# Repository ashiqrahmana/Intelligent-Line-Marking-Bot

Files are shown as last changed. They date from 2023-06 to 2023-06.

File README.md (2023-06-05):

# iLMBt - Intelligent Line Marking Bot
iLMBt (intelligent Line Marking Bot) is an autonomous wheeled mobile robot designed specifically for marking lines on sports fields without the need for human intervention. This GitHub repository contains all the necessary code, documentation, and design files to build and operate the iLMBt robot.

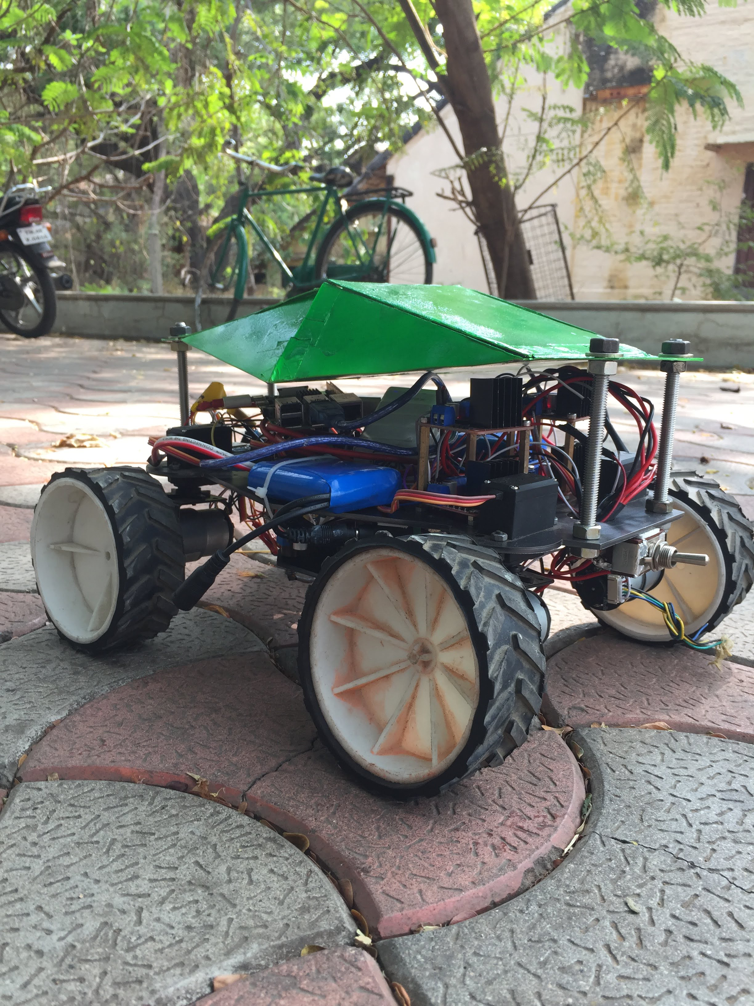
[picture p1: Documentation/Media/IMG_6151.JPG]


## Project Overview
The primary objective of iLMBt is to automate the line marking process in sports fields. By eliminating the need for human labor, iLMBt offers increased efficiency, precision, and reliability in line marking tasks. The robot utilizes a hopper mechanism controlled by a motorized lead screw to control the flow of marking powder. It also incorporates an effective dampening system for smooth and consistent line marking operations.

## Features
* **Autonomous line marking**: iLMBt is capable of autonomously marking lines on sports fields based on given coordinates. It calculates the desired path and precisely marks the required lines.
* **Collision avoidance**: The robot is equipped with a collision avoidance program that works in conjunction with the path tracking algorithm. This allows iLMBt to maneuver smoothly around obstacles while reaching the designated starting point.
* **Improved accuracy**: With the use of advanced navigation technologies such as GPS, IMU, and encoders, iLMBt ensures high accuracy in line marking, resulting in professionally marked sports fields.
* **Sensor integration**: iLMBt incorporates various sensors, including LIDAR, for obstacle avoidance and local mapping. These sensors enable the robot to navigate safely and efficiently. Accurate localisation was achieved using Kalman filter.

## Hardware and Electronics
* **Raspberry Pi**: The Raspberry Pi serves as the main controller for iLMBt, handling higher-level tasks such as path planning and communication.
* **Arduino Mega**: The Arduino Mega is responsible for low-level control and interfacing with the robot's actuators and sensors.
* **GPS**: A GPS module is used for global positioning, allowing iLMBt to determine its precise location on the sports field.
* **IMU**: An IMU (Inertial Measurement Unit) provides orientation and motion data, contributing to accurate navigation.
* **Encoder**: Encoders are employed for precise wheel odometry, enabling the robot to track its position and distance traveled.
* **LIDAR**: The LIDAR sensor enables iLMBt to detect obstacles and create a local map of its surroundings for effective collision avoidance.

## Contributions
Contributions to the iLMBt project are welcome! If you have any improvements, bug fixes, or new features to contribute, please follow the guidelines outlined in the Contribution document. Your contributions will be greatly appreciated and help advance the capabilities of iLMBt.

## Contact
For any questions, suggestions, or collaborations, please feel free to contact the project maintainers:

Ashiq Rahman: ashiqrahmanab@gmail.com
Thank you for your interest in iLMBt! We hope this project brings automation and improved line marking capabilities to sports fields worldwide.

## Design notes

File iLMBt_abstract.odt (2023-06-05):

iLMBt

iLMBt (intelligent Line Marking Bot) is an autonomous wheeled mobile robot that is modeled and designed to mark the lines of sports fields without any human intervention.

A hopper mechanism is built in to control the flow of powder, which is controlled by a motorized lead screw. An effective dampening system is designed for the smooth operation of the robot.

With the given coordinates, iLMBt calculates the desired path and the required line is marked.

A collision avoidance program is included with the path tracking algorithm to smoothly maneuver around obstacles while reaching the required starting point.

iLMBt eliminates the human labor in marking sports fields and also improves the accuracy of the lines.

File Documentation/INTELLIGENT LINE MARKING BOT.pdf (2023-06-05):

## INTELLIGENT LINE MARKING BOT

Team member details:

S.No | Name | Roll Number | Year | Department | Mail ID | Phone Number
1. | Ashiq Rahman.A | 2018111015 | 3 | Mechanical | ashiqrahman741 @gmail.com | 6379404556
2. | Rajadurai.B | 2018111086 | 3 | Mechanical | brdrccegmotorsp orts@gmail.com | 9488624177
3. Vasanth | Kumar.V | 2019105064 | 2 | Electronics and Communication | vasanthvv1717 @gmail.com | 9445032825
4. Nithish | Narayan.S | 2019118020 | 2 | Mechanical | nithishnarayan2 001@gmail.com | 7358129293
5. Harshaward | han.K.U | 2018111044 | 3 | Mechanical | harshaku2001@ gmail.com | 6385666123
6. | Veniniyan.V | 2018111127 | 3 | Mechanical | veniniyan1729 @gmail.com | 8248725604
7. | Vallarasu.K | 2018111125 | 3 | Mechanical | vallarasukumar2 001@gmail.com | 7339074190

Abstract:

Nowadays, robots are used in different areas for different applications. The problem is to mark field lines manually in a sports field, especially on gravel or sand fields, which can lead to errors and high time consumption. This project thus focuses on a stand-alone line marking robot, which can easily complete this process. This robot is intended to provide accurate marking of any field within a shorter time frame by using sensor fusion algorithms to fuse various sensors to pinpoint the location of the robot. The simulation of the robot is performed in the Matlab - Simulink software with the help of existing libraries. After the simulation, the code is checked on a real robot. The mechanical team developed the design. Adequate suspension and steering mechanisms will be provided to overcome the unequal nature of ground or soil. Finally, the code has been optimised and tested in the field to achieve the desired precision.

YouTube Link and Website Link:

Bot | CTF Projects | Kurukshetra '21 - YouTube (https://www.youtube.com/watch?v=S4F7P6YnfdU&ab_channel=KurukshetraCEG)

Link to the LOA folder:

Timeline:

DECEMBER | Simulation on MATLAB - SIMULINK software.
JANUARY | Initial Design and Testing iterations of the bot in CAD software

FEBRUARY | Final Design and Testing iterations of the bot in CAD software
MARCH | Assembly and Testing of the Bot

SPLIT UP WORKS: -

We, the team members, had a number of brainstorming sessions on G-Meet. Analysed the pros and cons of different components and concepts used in the bot.

We internally split up our work as two parts

a) Design Team
b) Simulation and Coding Team

Though we split work among ourselves, we consistently had many meetings during weekdays and weekends to share our work process and had many discussions on the improvement of the bot.

DECEMBER (SIMULATION): -

WEEK 1: -

The Problem statement was further analysed and tried to formulate the most feasible solution with the team. Discussed about the essential works to be done for the bot’s successful operation.

WEEK 2: -

Initial iteration of the pre-path planning algorithm was done. This includes creating way points for the bot to trace.

WEEK 3: -

The code for the pre-path planning algorithm was successfully finished.

WEEK 4: -

Initial iteration of Sensor fusion of Magnetometer, Gyroscope and Accelerometer was simulated in MATLAB.

JANUARY (DESIGN AND TESTING): -

WEEK 1: -

Sensor fusion was successfully simulated in MATLAB. Noise of the sensor was reduced by different filters.

WEEK 2: -

Analysed and discussed with the team about the designing works of the bot and initial iterations of design were formed.

Potential components required were drafted.

WEEK 3: -

1. Finished the CAD design works of iLMBT.
2. Analysed the CAD model and its performance on the track.
3. Done important calculations and analysis in kinematics.

WEEK 4: -

1. According to the calculation the bot was completely redesigned.
2. Finalize the chassis, wheelbase, knuckle type
3. And materials were selected for each and every major component.

FEBRUARY (DESIGN AND TESTING Contd.): -

WEEK 1: -

Many design iterations were made to rectify all the minute corrections.

WEEK 2: -

Studied about the closing and opening of the powder entrance. And finalized to use the Hopper mechanism and studied it further.

WEEK 3: -

1. Finalized the components required and suitable for the Hopper mechanism like N20 motor (to open and close the hopper slot) and calculated the dimensions of the slots needed.
2. Servo motors were used for steering of each wheel, it can make upto 45 degrees of rotation.

WEEK 4: -

Finalised the materials and dimensions suitable for the chassis tank. Did some mass calculations on the hole (where the powder will be deployed) of iLMBT.

MARCH (ASSEMBLY AND TESTING): -

WEEK 1: -

- Electronic component mounting design was added to the existing design of the bot.
- Several iterations of the design were done for effective placement of the electronic components.

WEEK 2: -

- The layout design for laser cut was done and it took a week to get all the material for laser cutting.
- All the electronic components of the bot arrived. Such as Arduino mega, Raspberry pi, Motor drivers, GPS Module, MPU 9250, Gyro, Servo motor for steering and wheels.
- Meanwhile the code was uploaded in Raspberry pi and Arduino and checked for errors and corrected.

WEEK 3: -

- The chassis of the bot was laser cut.

- The fit and tolerance of the electronic component was tested with the chassis of the bot.
- Initial assembly of the electronics was made and all the parts were tested. Such as a GPS module.
- All necessary parts of the bot arrived such as Wheels, rechargeable batteries.
- The holes in the chassis were 2.7mm but the actual diameter needed was 3mm. So, the chassis was drilled to enlarge the dimensions.
- The wheels were attached to the chassis with servo to check the camber of the wheels and the deflection of the chassis.

WEEK 4: -

- The casing of the bot was done.
- The bot was checked for steering and GPS status.
- The initial testing of the bot was done on the field.
- All the wires are disassembled and proper soldering was done.
- Hopper mechanism was fixed and the top case was attached to the bot.
- The bot was finished with all required parts and assembly.

Budget:

S.N o. | Component Name | Shop Name with Location | Per Unit Price | Quantity | Net Price
1. | MPU 9250 | Mercy Electronics | Rs.661.02 | 1 | Rs.661.02
2. P.Kit GPS Flight | Control | Mercy Electronics | Rs.406.78 | 1 | Rs.406.78
3. Triple axis Gyro | Accelerometer Module | ElectronicsComp.in | Rs.83.00 | 1 | Rs.83.00

4. Triple axis Compass | Magnetometer Sensor Module | ElectronicsComp.in | Rs.210.00 | 1 | Rs.210.00
5. | Arduino Mega | ElectronicsComp.in | Rs.695.00 | 1 | Rs.695.00
6. Raspberry Pi 4 Model B | with 2GB Ram | ElectronicsComp.in | Rs.2,895.00 | 1 | Rs.2,895.00
7. GA12 N20 12V | 140RPM All metal Gear Micro DC Encoder Motor | Dazzle Robotics | Rs.380.00 | 6 | Rs.2,280.00
8. Charger for | Rechargeable batteries | Amazon.in | Rs.675.00 | 1 | Rs.675.00
9. | TS10A 2P2W | Ponniie Electrical and Electronics | Rs.60.00 | 3 | Rs.212.40
10. Rhino GB37 12V | 110RPM 6.5KGCM DC Geared Encoder Servo Motor | Dazzle Robotics | Rs.810.00 | 4 | Rs.3,240.00
11. Li-ion 11.1V 2500mAh | (2C) with inbuilt charger protection | Dazzle Robotics | Rs.713.00 | 3 | Rs.2,139.00
12. Bracket for High | Torque/Side shaft Motor | Dazzle Robotics | Rs.120.00 | 4 | Rs.480.00
13. Jumper Cable Male to | Male | Mercy Electronics | Rs.135.69 | 1 | Rs.135.69

14. Jumper Cable Female to | Male | Mercy Electronics | Rs.5.60 | 10 | Rs.50.60
15. Jumper Cable Female to | Female | Mercy Electronics | Rs.5.60 | 10 | Rs.50.60
16. | Battery 9V | Mercy Electronics | Rs.12.71 | 1 | Rs.12.71
17. | Battery Snap 9V | Mercy Electronics | Rs.4.24 | 1 | Rs.4.24
18. Rhino DC Servo Driver | 50W | Dazzle Robotics | Rs.478.00 | 4 | Rs.1912.00
19. Hopper Made of | Aluminium Sheet | JNS Metals | Rs.275.00 | 0.95Kg | Rs.275.00
20. | Chassis Laser cut | Dhanalakshmi Industries | Rs.1391.00 | 1 | Rs.1391.00
21. Stud and M8 Bolt and | Nut | Sri Velavan Engineering Works | Rs.130.00 | 4 | Rs.520.00
22. | M6 Bolt and Nut | Raj Industrial Enterprises | Rs.90.00 | 1 | Rs.90.00
25. | M2 Bolt and Nut | Raj Industrial Enterprises | Rs.3.00 | 10 | Rs.30.00
26. Tracked Wheels of | 110mm Diameter 45mm Width and 6mm ID | Dazzle Robotics | Rs.130.00 | 4 | Rs.520.00

27. | 6 SS Allen Bolt | AR Traders | Rs.2.15 | 60 | Rs.129.00
28. | 8 SS Allen Bolt | AR Traders | Rs.2.20 | 25 | Rs.55.00
29. | 12 SS Allen Bolt | AR Traders | Rs.2.25 | 20 | Rs.45.00
30. | P.Kit Robot Chassis | Mercy Electronics | Rs.338.00 | 1 | Rs.338.00
31. | 15 SS Allen Bolt | AR Traders | Rs.4.50 | 20 | Rs.90.00
32. | 3mm GP Nut | AR Traders | Rs.0.25 | 40 | Rs10.00
33. | Memory Card 32GB | Poorvika Mobiles | Rs.600.00 | 1 | Rs.600.00
34. Material Milling and | Lathe Work | Skilled Engineering | Rs.600.00 | 1 | Rs.600.00
35. Electric Soldering Iron | Kit | Amazon.in | Rs.799.00 | 1 | Rs.799.00
36. | P.Kit Board | Mercy Electronics | Rs.161.00 | 1 | Rs.161.00
Total | | | | | Rs.21,795.64

Technical Explanation:

The Intelligent Line Marking bot (iLMBT) uses dynamic path planning algorithm, to plan the path in real time by avoiding obstacles and decreasing the time of line marking.

The bot uses Kalman filter which is a digital filter that filters error by accounting the probabilistic error of the GPS sensor (which has an accuracy of only 2.5m), IMU sensor which estimates to increase the accuracy to centimeter scale.

The bot has three sensors, they are GPS module, MPU9250 (which measures the angular velocity hence the rotation of the bot), and inbuilt compass to assess the orientation of the bot. The bot uses Akermann steering and Differential steering for kinematics of the system. It has a hopper tank with a capacity of 1.5 Kg, which helps in storage of line marking powder with minimal human interference. And this bot also has a ground clearance of 4.5m, which helps the bot work in uneven terrain. The bot uses N20 motors for smooth deployment of the powder in the field.

Photos of Components:

MPU 9250:

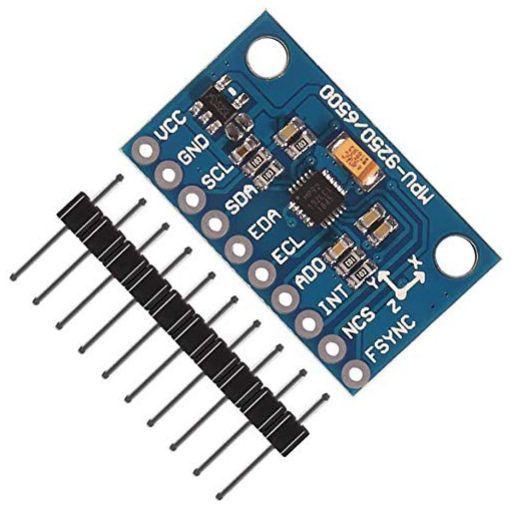
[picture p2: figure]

GPS module:

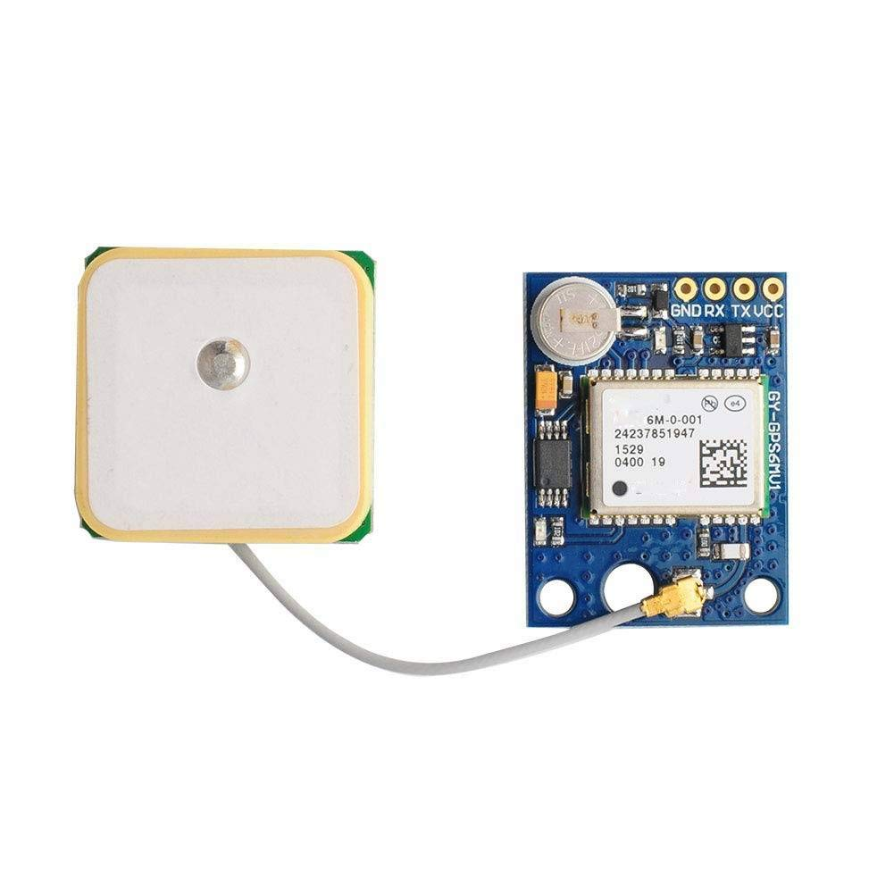
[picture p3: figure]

ARDUINO MEGA:

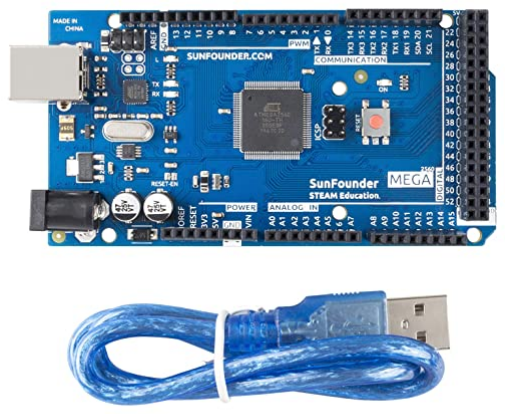
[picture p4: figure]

MOTOR DRIVER: -

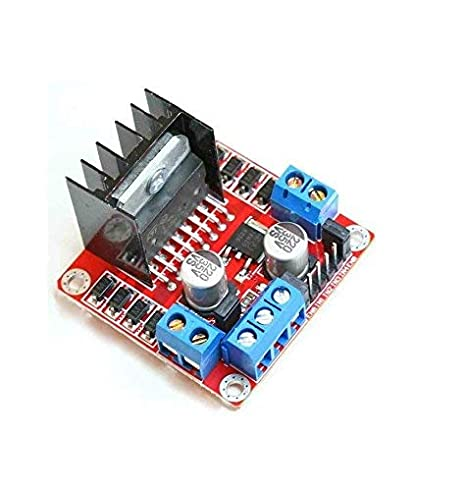
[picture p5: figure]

Triple axis Gyro Accelerometer Module: -

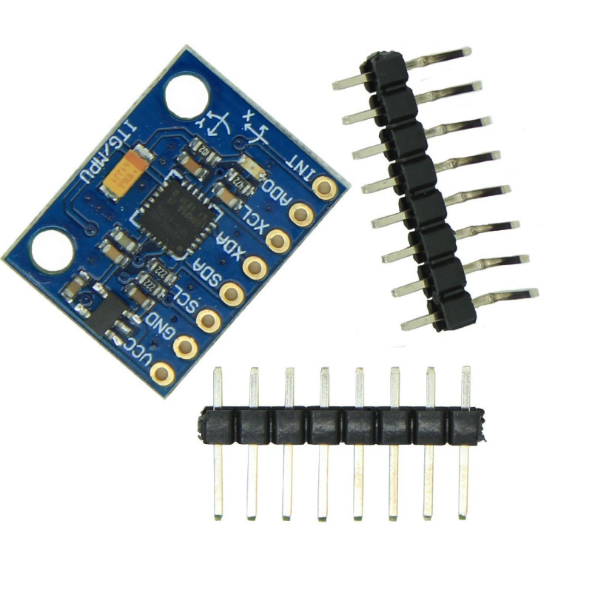
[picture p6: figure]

Analysis and Obtained Conclusions:

A1. The Kalman Filter has a large error to correct then usual mostly due to the present of trees

A2. There was a lot of vibration in the bot in general which should have been due to the lack of weight of the bot which lead to slipping of the wheel

Problems and Obtained Solutions:

P1. Actual dimension of the bot was not built.

P2. The deployment of line marking powder was not demonstrated.

P3. Obstacle detecting sensor was not added.

P4. Kalman filter was not tuned to full efficiency

Result:

The iLMBT was able to locate and move to two points successfully

Future Work:

- The iLMBT would be upgraded in size
- The steering motors will be upgraded due to less resolution in the present one
- Suspension systems are yet to added
- IOT code for the bot has to be done
- proper ventilation
- user interface

Attachment Details:

Team Folder -
https://drive.google.com/drive/folders/1LOc3MQuMsQAj66ATGowux1fOUP3XBcpq?usp=sharing (https://drive.google.com/drive/folders/1LOc3MQuMsQAj66ATGowux1fOUP3XBcpq?usp=sharing)

Media Folder -

https://drive.google.com/drive/folders/1bKW9zVyGzebHwZNid_FVrjj-9Q9dmMdC?usp=sharing (https://drive.google.com/drive/folders/1bKW9zVyGzebHwZNid_FVrjj-9Q9dmMdC?usp=sharing)

Guided By:

CTF Projects Student Directors

Sivakumar.S

Balaji.S

Hitesh Ram.A.K

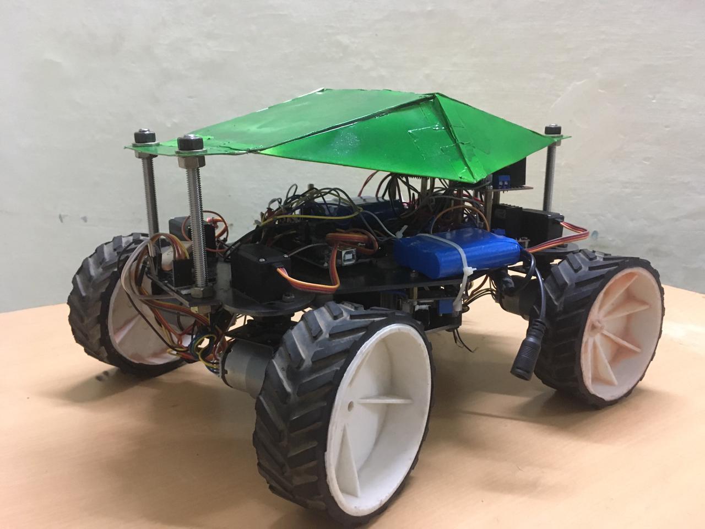
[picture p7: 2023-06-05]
Documentation/Media/WhatsApp Image 2021-03-28 at 3.16.44 AM.jpeg

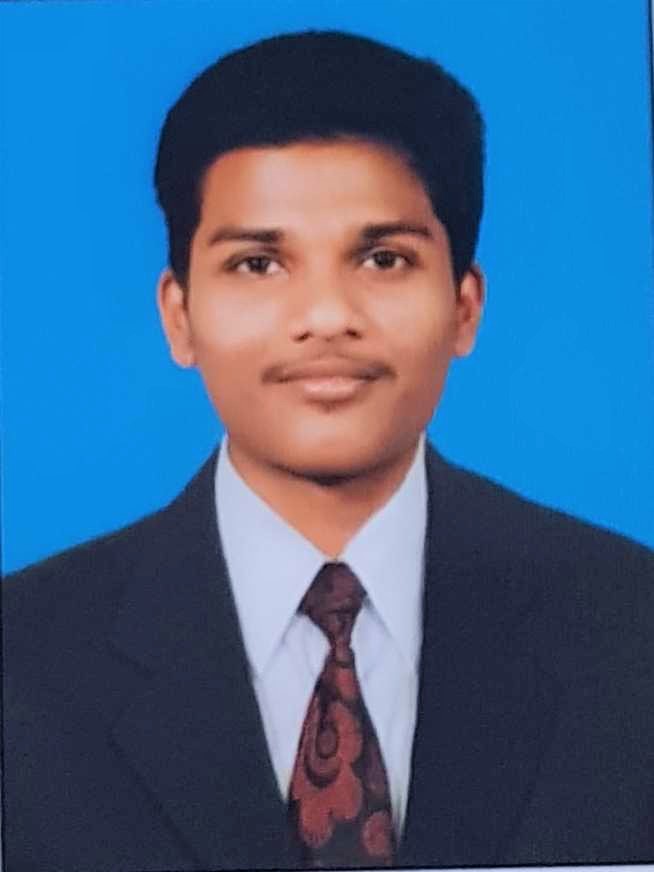
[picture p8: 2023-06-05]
Documentation/Team/Harshwardhan.jpeg

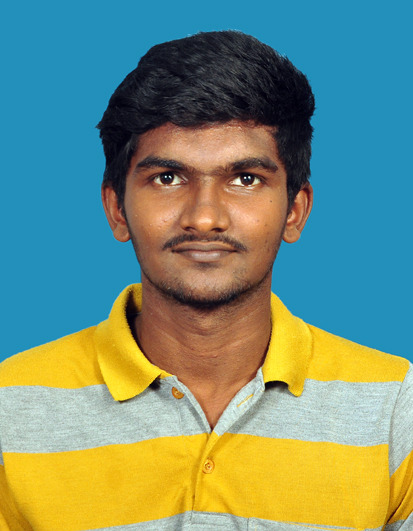
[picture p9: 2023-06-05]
Documentation/Team/Vasanth.jpeg

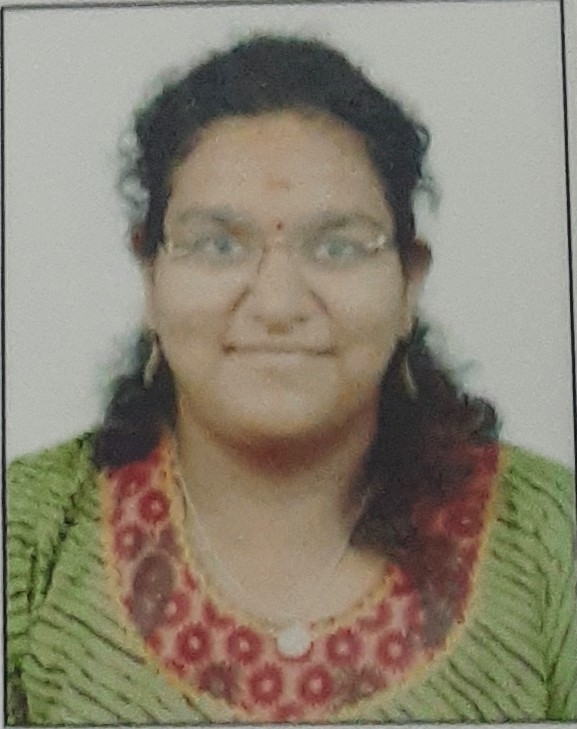
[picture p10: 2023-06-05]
Documentation/Team/Padmaja.jpg

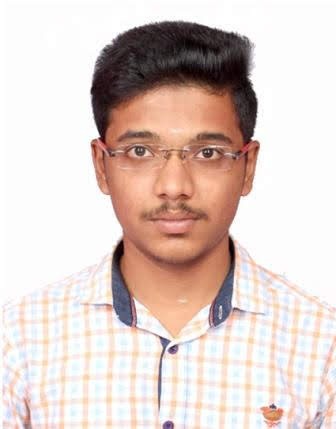
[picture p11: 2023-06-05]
Documentation/Team/Rajadurai.jpeg

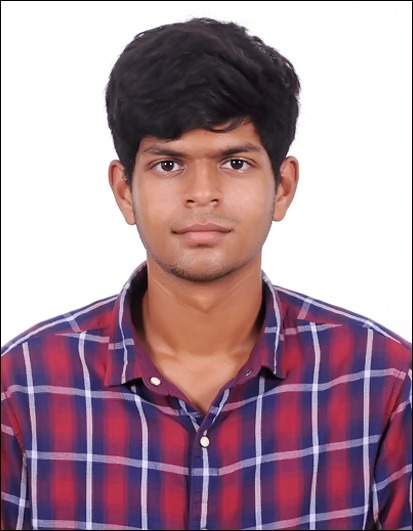
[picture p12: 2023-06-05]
Documentation/Team/Abdullah.jpeg

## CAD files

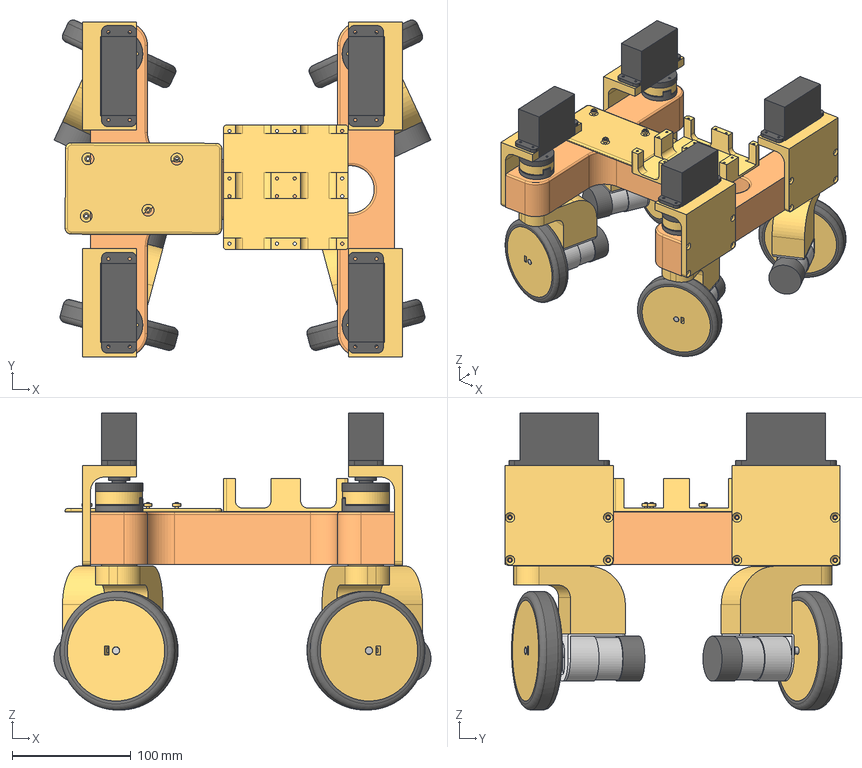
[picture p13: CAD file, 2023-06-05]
Design/3D cad xrobot version/OnmiSwerve-main/CAD/4_WheelsSwerve01.stp
317.7 x 284.0 x 250.2 mm
wheel
wheel(Mirror)
wheel(Mirror) (1)
wheel(Mirror)(Mirror)

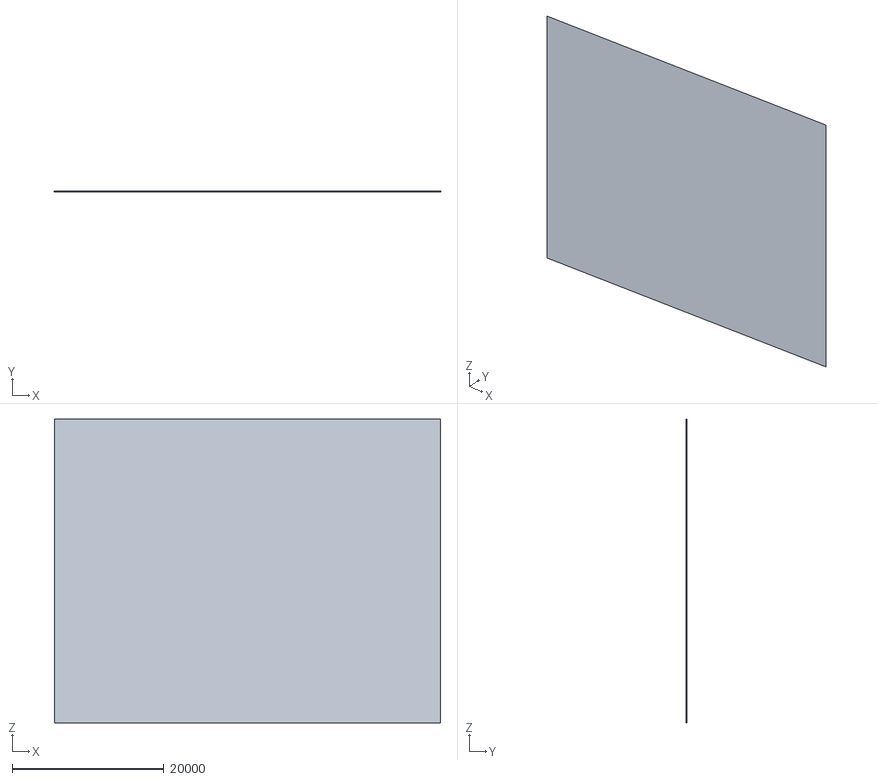
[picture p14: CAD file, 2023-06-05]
Design/Ground_Hockey/Ground.stl
50798.3 x 1.00 x 40005.7

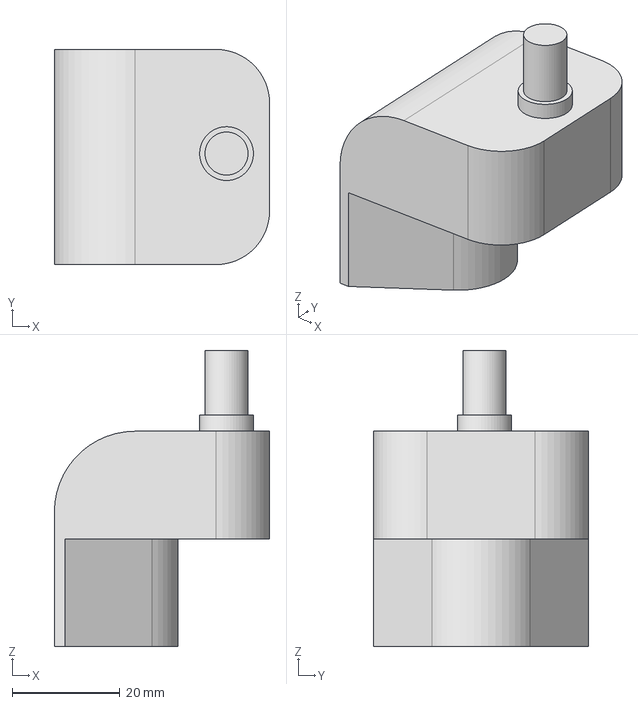
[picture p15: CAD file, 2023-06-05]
Design/ilmbt_3d_v1/servo_shaft.stp
40.0 x 40.0 x 55.0 mm

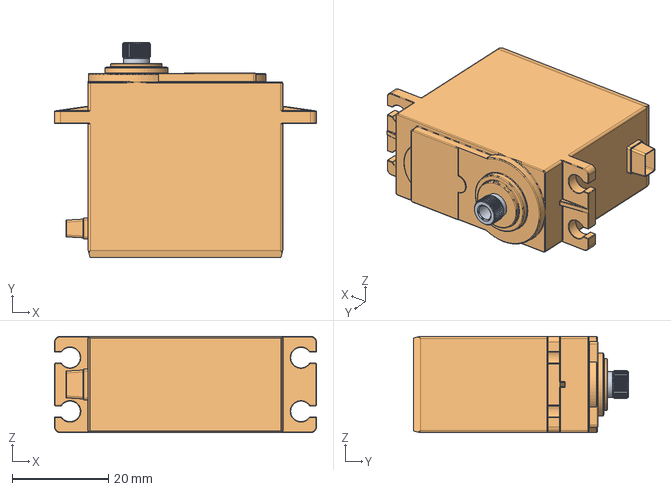
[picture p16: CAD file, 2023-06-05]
Design/LMBOT V3 80%/MG-958 servo_MIR.stp
54.4 x 44.6 x 20.0 mm
Golden part_MIR
Part13_MIR

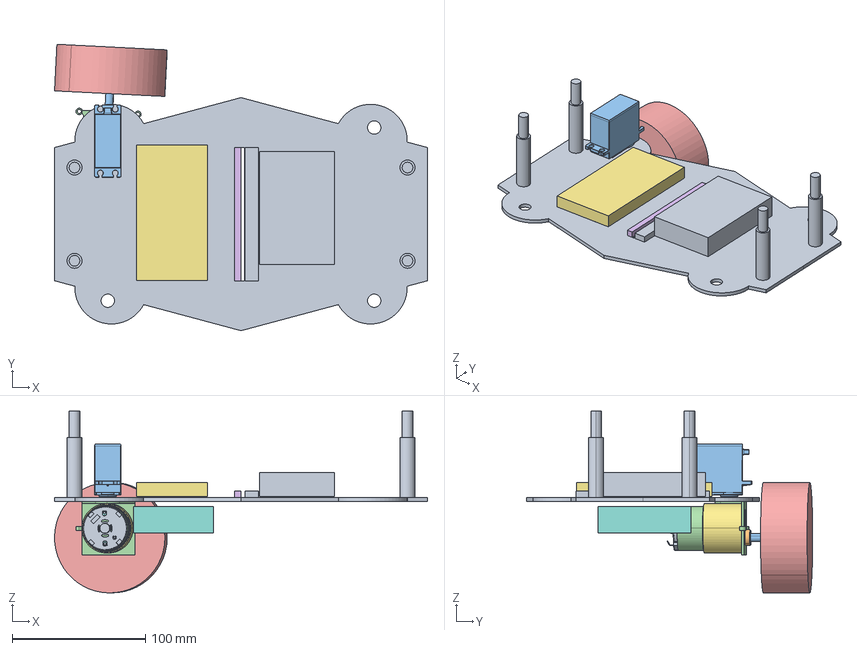
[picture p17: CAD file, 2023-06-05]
Design/LMbot V3/LMbot V3.stp
280.0 x 215.0 x 136.5 mm

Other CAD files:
Design/3D cad xrobot version/OnmiSwerve-main/CAD/4_WheelsSwerve01.iam
Design/3D cad xrobot version/OnmiSwerve-main/CAD/OldVersions/4_WheelsSwerve01.0007.iam
Design/3D cad xrobot version/OnmiSwerve-main/CAD/OldVersions/Part1.0002.ipt
Design/3D cad xrobot version/OnmiSwerve-main/CAD/OldVersions/Part10.0007.ipt
Design/3D cad xrobot version/OnmiSwerve-main/CAD/OldVersions/wheel(Mirror) (1).0001.ipt
Design/3D cad xrobot version/OnmiSwerve-main/CAD/OldVersions/wheel(Mirror)(Mirror).0001.ipt
Design/3D cad xrobot version/OnmiSwerve-main/CAD/OldVersions/wheel(Mirror).0001.ipt
Design/3D cad xrobot version/OnmiSwerve-main/CAD/OldVersions/wheel.0001.ipt
Design/3D cad xrobot version/OnmiSwerve-main/CAD/Part1.ipt
Design/3D cad xrobot version/OnmiSwerve-main/CAD/Part10.ipt
Design/3D cad xrobot version/OnmiSwerve-main/CAD/wheel(Mirror) (1).ipt
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

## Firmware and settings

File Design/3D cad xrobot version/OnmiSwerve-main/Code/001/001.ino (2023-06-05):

#include <Servo.h>

Servo servo1;
Servo servo2;
Servo servo3;
Servo servo4;

int wheel1;
int wheel1a;
int wheel2;
int wheel2a;

// Radio
#include <SPI.h>
#include <nRF24L01.h>
#include <RF24.h>

RF24 radio(7, 8); // CE, CSN
const byte addresses[][6] = {"00001", "00002"};

//**************remote control****************
struct RECEIVE_DATA_STRUCTURE{
  //put your variable definitions here for the data you want to send
  //THIS MUST BE EXACTLY THE SAME ON THE OTHER ARDUINO
    int16_t menuDown;  
    int16_t Select;    
    int16_t menuUp;  
    int16_t toggleBottom;  
    int16_t toggleTop; 
    int16_t toggle1;
    int16_t toggle2;
    int16_t mode;  
    int16_t RLR;
    int16_t RFB;
    int16_t RT;
    int16_t LLR;
    int16_t LFB;
    int16_t LT;
};

RECEIVE_DATA_STRUCTURE mydata_remote;

int RLR = 0;
float RFB = 0;
float RFBa = 0;
int RT = 0;
int LLR = 0;
int LFB = 0;
int LT = 0;
int LTa = 0;

float cor;
float insideAngle;
float outsideAngle;
float insideAngleOutput;
float outsideAngleOutput;
float insideVel;
float outsideVel;

unsigned long currentMillis;
long previousMillis = 0;    // set up timers
long interval = 10;        // time constant for timer

int servo1Offset = 1430;
int servo2Offset = 1375;
int servo3Offset = 1470;
int servo4Offset = 1500;

int servo45 = 400;

void setup() {

    pinMode(5, OUTPUT);
    pinMode(6, OUTPUT);
    pinMode(9, OUTPUT);
    pinMode(10, OUTPUT);
   
    // initialize serial communication
    Serial.begin(115200);
    
    radio.begin();
    radio.openWritingPipe(addresses[0]); // 00002
    radio.openReadingPipe(1, addresses[1]); // 00001
    radio.setPALevel(RF24_PA_MIN);
    radio.startListening();

    pinMode(3, OUTPUT);
    pinMode(4, OUTPUT);
    pinMode(5, OUTPUT);
    pinMode(6, OUTPUT);

    pinMode(9, OUTPUT);
    pinMode(10, OUTPUT);
    pinMode(11, OUTPUT);
    pinMode(12, OUTPUT);

    servo1.attach(32);
    servo2.attach(34);
    servo3.attach(36);
    servo4.attach(38);

    servo1.writeMicroseconds(servo1Offset);
    servo2.writeMicroseconds(servo2Offset);
    servo3.writeMicroseconds(servo3Offset);
    servo4.writeMicroseconds(servo4Offset);      


    
}   // end of setup

// ********************* MAIN LOOP *******************************

void loop() {  

      
        currentMillis = millis();
        if (currentMillis - previousMillis >= 20) {  // start timed event
          
            previousMillis = currentMillis;


            // check for radio data
            if (radio.available()) {
                    radio.read(&mydata_remote, sizeof(RECEIVE_DATA_STRUCTURE));   
            }             

            else {
              Serial.println("no data");
            }

            // threshold remote data
            // some are reversed based on stick wiring in remote
            RFB = (thresholdStick(mydata_remote.RFB))/2;   
            RLR = (thresholdStick(mydata_remote.RLR))/2;
            LT = (thresholdStick(mydata_remote.LT))/2;
            LLR = (thresholdStick(mydata_remote.LLR))/2; 


            if (mydata_remote.toggleTop == 1) {                       // rotate on the spot
                  
                servo1.writeMicroseconds(servo1Offset + servo45);
                servo2.writeMicroseconds(servo2Offset - servo45);
                servo3.writeMicroseconds(servo3Offset - servo45);
                servo4.writeMicroseconds(servo4Offset + servo45); 

                LT = LT / 1.5;        // scale driving stick some more

               if (LT >=0) {
                  LTa = abs(LT);
                  analogWrite(4, LTa);       // wheel 1
                  analogWrite(3, 0);
                  analogWrite(6, LTa);       // wheel 2
                  analogWrite(5, 0);
                  analogWrite(9, 0);       // wheel 3
                  analogWrite(10, LTa);
                  analogWrite(11, 0);       // wheel 4
                  analogWrite(12, LTa);
                  
                }

                else if (LT <=0) {
                  LTa = abs(LT);
                  analogWrite(4, 0);          // wheel 1
                  analogWrite(3, LTa);
                  analogWrite(6, 0);          // wheel 2
                  analogWrite(5, LTa);
                  analogWrite(9, LTa);       // wheel 3
                  analogWrite(10, 0);
                  analogWrite(11, LTa);       // wheel 4
                  analogWrite(12, 0);
                  
                }                         
            }

            else {                                                  // swerve steering

                // trig calcs for Ackermann steering
                
                cor = 1000-abs(LLR*3.5);                            // scale centre of rotation from stick

                insideAngle = atan(104 / (cor - 114));              // calc angle in radians
                insideAngle = insideAngle * (180/PI);               // convert to degrees    

                outsideAngle = atan(104 / (cor + 114));
                outsideAngle = outsideAngle * (180/PI);

                outsideAngle = outsideAngle * 9;                    // convert to servo ms
                insideAngle = insideAngle * 9;                      // convert to servo ms

                if (LLR == 0) {
                  insideAngleOutput = 0;                            // steer straight when the stick is in the middle
                  outsideAngleOutput = 0;
                } 
                else if (LLR >=0) {
                  insideAngleOutput = outsideAngle*-1;              // invert angles when we steer the other way
                  outsideAngleOutput = insideAngle*-1;
                }
                else if (LLR <=0) {
                  insideAngleOutput = insideAngle;                  // angles can be used for the default side of the vehicle as they are
                  outsideAngleOutput = outsideAngle;
                }

                Serial.print(insideAngle);
                Serial.print(" , ");
                Serial.println(outsideAngle);
 
           
                servo1.writeMicroseconds(servo1Offset + (LT * 3.8) - insideAngleOutput);        // write out the servo positions
                servo2.writeMicroseconds(servo2Offset + (LT * 3.8) + insideAngleOutput);        // use the left twist stick for swerve steering
                servo3.writeMicroseconds(servo3Offset + (LT * 3.8) - outsideAngleOutput);       // and use the angle calc for Ackermann steering.
                servo4.writeMicroseconds(servo4Offset + (LT * 3.8) + outsideAngleOutput); 



                insideVel = float ((RFB/100)*outsideAngle);
                outsideVel = float ((RFB/100)*insideAngle);
                insideVel = constrain(insideVel,-255,255);
                outsideVel = constrain(outsideVel,-255,255);



                // write to motors 
               if (LLR == 0) {

                  // *** straight line ***

                  RFB = RFB * 0.5;          // scale throttle a little more
               
                  if (RFB > 0) {
                    RFBa = abs(RFB);
                    analogWrite(3, RFBa);       // wheel 1
                    analogWrite(4, 0);
                    analogWrite(5, RFBa);       // wheel 2
                    analogWrite(6, 0);
                    analogWrite(9, 0);       // wheel 3
                    analogWrite(10, RFBa);
                    analogWrite(11, 0);       // wheel 4
                    analogWrite(12, RFBa);                  
                  }
                  // backwards  
                  else if (RFB < 0) {
                    RFBa = abs(RFB);
                    analogWrite(3, 0);          // wheel 1
                    analogWrite(4, RFBa);
                    analogWrite(5, 0);          // wheel 2
                    analogWrite(6, RFBa);
                    analogWrite(9, RFBa);       // wheel 3
                    analogWrite(10, 0);
                    analogWrite(11, RFBa);       // wheel 4
                    analogWrite(12, 0);                  
                  }
                // stop
                    else {
                      analogWrite(3, 0);          // wheel 1
                      analogWrite(4, 0);
                      analogWrite(5, 0);          // wheel 2
                      analogWrite(6, 0);
                      analogWrite(9, 0);       // wheel 3
                      analogWrite(10, 0);
                      analogWrite(11, 0);       // wheel 4
                      analogWrite(12, 0);
                    }
              }


              if (LLR > 0) {  // *** steer right ***                     

                  // forwards
               
                  if (RFB > 0) {
                    outsideVel = abs(outsideVel);
                    insideVel = abs(insideVel);
                    analogWrite(3, outsideVel);       // wheel 1
                    analogWrite(4, 0);
                    analogWrite(5, outsideVel);       // wheel 2
                    analogWrite(6, 0);
                    analogWrite(9, 0);       // wheel 3
                    analogWrite(10, insideVel);
                    analogWrite(11, 0);       // wheel 4
                    analogWrite(12, insideVel);                  
                  }
                  // backwards  
                  else if (RFB < 0) {
                    outsideVel = abs(outsideVel);
                    insideVel = abs(insideVel);
                    analogWrite(3, 0);          // wheel 1
                    analogWrite(4, outsideVel);
                    analogWrite(5, 0);          // wheel 2
                    analogWrite(6, outsideVel);
                    analogWrite(9, insideVel);       // wheel 3
                    analogWrite(10, 0);
                    analogWrite(11, insideVel);       // wheel 4
                    analogWrite(12, 0);                  
                  }
                // stop
                    else {
                      analogWrite(3, 0);          // wheel 1
                      analogWrite(4, 0);
                      analogWrite(5, 0);          // wheel 2
                      analogWrite(6, 0);
                      analogWrite(9, 0);       // wheel 3
                      analogWrite(10, 0);
                      analogWrite(11, 0);       // wheel 4
                      analogWrite(12, 0);
                    }
              }

              if (LLR <0) {  // *** steer left ***                      

                  // forwards
               
                  if (RFB > 0) {
                    outsideVel = abs(outsideVel);
                    insideVel = abs(insideVel);
                    analogWrite(3, insideVel);       // wheel 1
                    analogWrite(4, 0);
                    analogWrite(5, insideVel);       // wheel 2
                    analogWrite(6, 0);
                    analogWrite(9, 0);       // wheel 3
                    analogWrite(10, outsideVel);
                    analogWrite(11, 0);       // wheel 4
                    analogWrite(12, outsideVel);                  
                  }
                  // backwards  
                  else if (RFB < 0) {
                    outsideVel = abs(outsideVel);
                    insideVel = abs(insideVel);
                    analogWrite(3, 0);          // wheel 1
                    analogWrite(4, insideVel);
                    analogWrite(5, 0);          // wheel 2
                    analogWrite(6, insideVel);
                    analogWrite(9, outsideVel);       // wheel 3
                    analogWrite(10, 0);
                    analogWrite(11, outsideVel);       // wheel 4
                    analogWrite(12, 0);                  
                  }
                // stop
                    else {
                      analogWrite(3, 0);          // wheel 1
                      analogWrite(4, 0);
                      analogWrite(5, 0);          // wheel 2
                      analogWrite(6, 0);
                      analogWrite(9, 0);       // wheel 3
                      analogWrite(10, 0);
                      analogWrite(11, 0);       // wheel 4
                      analogWrite(12, 0);
                    }
              }

            }


                          
                



      
        }     // end of timed loop         

   
}       // end  of main loop

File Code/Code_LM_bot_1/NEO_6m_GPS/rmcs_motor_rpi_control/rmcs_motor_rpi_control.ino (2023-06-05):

/*
#include<RMCS2303drive.h>
#include<stdint.h>

//----------------------------------------------------------------
//#defines
//----------------------------------------------------------------
#define SLAVE1        0
#define SLAVE2        1

#define IGAIN         32
#define DGAIN         16
#define LPR           11
#define ACCELERATION  20000

//----------------------------------------------------------------
//Structure definition
//----------------------------------------------------------------
typedef struct{
#define PGAIN         100
  long int currentPosition, currentSpeed;
}motorFeedback;

//----------------------------------------------------------------
//Function declaration
//----------------------------------------------------------------
void waitTillPositionReached(long int);

//----------------------------------------------------------------
//Global variables
//----------------------------------------------------------------
RMCS2303 motor;
motorFeedback slave[2];
int slaveID = 7;

//----------------------------------------------------------------
//Setting up Software Serial communication
//----------------------------------------------------------------
SoftwareSerial myserial(2, 3);      //RX - 2, TX - 3



void setup() {
  //Initiating Serial Communication with Motor Driver RMCS2303
  motor.Serial_selection(1);
  motor.begin(&myserial, 9600);

  Serial.begin(115200);
  motor.WRITE_PARAMETER(slaveID, 0x0101, PGAIN, IGAIN, DGAIN, LPR, ACCELERATION, 3000); //Initialized motor in Postion Control mode disabled
  //motor.SET_HOME(slaveID);
  

  //motor.Enable_Digital_Mode(slaveID, 0);
  
 }

void loop() {
    
    long int speedFeedback = motor.Speed_Feedback(slaveID);
    String toBeSent = String(speedFeedback)+'\n';
    Serial.print(toBeSent);
    //motor.Speed(7, 10);
    /*
    if(Serial.available()>0){
      String inputSpeed = Serial.readStringUntil('\n');
      motor.Speed(slaveID, inputSpeed.toInt());  
      //delay(2000);
    }
}
//----------------------------------------------------------------
//Function definition
//----------------------------------------------------------------
void waitTillPositionReached(long int pos){
          uint8_t positionReached;
          long int positionDifference;
          while(1){
          for(slaveID = 1; slaveID <= 2; slaveID++){
            
            slave[slaveID-1].currentPosition = motor.Position_Feedback(slaveID);
            positionDifference =  motor.Position_Feedback(slaveID) - slave[slaveID-1].currentPosition;

            positionDifference = (positionDifference < 0)? -positionDifference: positionDifference;
            positionReached = (positionDifference < 20)? 1 : 0;
            
            slave[slaveID-1].currentSpeed = motor.Speed_Feedback(slaveID);
          }
          
          if(positionReached){
            break;
          }
        }
}*/
/*
Connections of Drive and Arduino
Serial Port 0 is not used to connect to drive because its connected to USB-Serial and used to show information on console.

For Arduino Uno Software serial needs to be used as there is only one hardware serial port and its connected to USB-Serial. 
   Drive to Arduino UNO/Nano connections
   GND         -      GND
   RXD         -      D3
   TXD         -      D2

For arduino mega and other arduinos with multiple hardware serial port, any port other than 0 can be selected to connect the drive.

   Drive to Arduino Mega2560 connections
   GND         -      GND
   RXD         -      Tx1/Tx2/Tx3
   TXD         -      Rx1/Rx2/Rx3
   
*  This mode can be used when multiple motors are to be used to run at exactly the same RPM and same torque even though the voltage supply might be different.
* Also in this mode the direction of the motor can be controlled digitally via modbus ASCII commands to run the dc servo motor in both directions

* For more information see : https://robokits.co.in/motor-drives-drivers/encoder-dc-servo/rhino-dc-servo-driver-50w-compatible-with-modbus-uart-ascii-for-encoder-dc-servo-motor


*/
/*
#include<RMCS2303drive.h>

RMCS2303 rmcs;                    //object for class RMCS2303

SoftwareSerial myserial(0,1);     //Software Serial port For Arduino Uno. Comment out if using Mega.

//parameter Settings "Refer datasheet for details"
byte slave_id=7 ;
int INP_CONTROL_MODE=257;           
int PP_gain= 100;
int PI_gain=32;
int VF_gain=16;
int LPR=11;
int acceleration=20000;
int speed_=9000;


long int Current_position;
long int Current_Speed;

void setup()
{
   Serial.begin(9600);
   rmcs.Serial_selection(1);       //Serial port selection:0-Hardware serial,1-Software serial
   rmcs.Serial0(9600);             //Set baudrate for usb serial to monitor data on serial monitor
   Serial.println("RMCS-2303 Speed control mode demo\r\n\r\n");
   Serial.println("-");
   //rmcs.begin(&Serial1,9600);    //Uncomment if using hardware serial port for mega2560:Serial1,Serial2,Serial3 and set baudrate. Comment this line if Software serial port is in use
   rmcs.begin(&myserial,9600);     //Uncomment if using software serial port. Comment this line if using hardware serial.
   Serial.println("-");
   rmcs.READ_PARAMETER(slave_id);
   Serial.println("-");
   rmcs.WRITE_PARAMETER(slave_id,INP_CONTROL_MODE,PP_gain,PI_gain,VF_gain,LPR,acceleration,speed_);    //Uncomment to write parameters to drive. Comment to ignore.
   //Serial.println("-");
}

void loop(void)
{
   Serial.println("looping bruh");
   Serial.println("Sending speed command - 8000 RPM");
   rmcs.Speed(slave_id,1000);                   //Set speed within range of 0-65535 or 0-(maximum speed of base motor)
   rmcs.Enable_Digital_Mode(slave_id,0);        //To enable motor in digital speed control mode. 0-fwd,1-reverse direction. 
   
   delay(3000);
   Current_Speed=rmcs.Speed_Feedback(slave_id); 
   Serial.print("Current Speed feedback : ");
   Serial.println(Current_Speed);

   delay(5000);
   Serial.println("Break Motor");
   rmcs.Brake_Motor(slave_id,0);                 //Brake motor. 0-fwd,1-reverse direction. 

   delay(2000);
   Serial.println("Changing direction");
   rmcs.Enable_Digital_Mode(slave_id,1);           //To enable motor in digital speed control mode. 0-fwd,1-reverse direction. 
}*/
#include<RMCS2303drive.h>
#include<stdint.h>

//----------------------------------------------------------------
//#defines
//----------------------------------------------------------------
#define SLAVE1        0
#define SLAVE2        1

#define PGAIN         100
#define IGAIN         32
#define DGAIN         16
#define LPR           11
#define ACCELERATION  20000

//----------------------------------------------------------------
//Structure definition
//----------------------------------------------------------------

//----------------------------------------------------------------
//Function declaration
//----------------------------------------------------------------
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

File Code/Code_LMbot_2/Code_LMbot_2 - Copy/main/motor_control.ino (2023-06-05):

// 512/360 = x/angle ==> angle = x*360/(512*4.8)
// angle/360 = dist / pi(D) 
//
//#include <PID_v1.h>
//
////Define Variables we'll be connecting to
//
//double Setpoint1,Setpoint2,Setpoint3,Setpoint4;
//double Input1,Input2,Input3,Input4;
//double Output1,Output2,Output3,Output4;
//double setpoint[4];
//
////Specify the links and initial tuning parameters
//double Kp[4] = {100,100,100,100};
//double Ki[4] = {50,50,50,50};
//double Kd[4] = {1,1,1,1};
//
//PID PID1(&Input1, &Output1, &Setpoint1, Kp[0], Ki[0], Kd[0], DIRECT);
//PID PID2(&Input2, &Output2, &Setpoint2, Kp[1], Ki[1], Kd[1], DIRECT);
//PID PID3(&Input3, &Output3, &Setpoint3, Kp[2], Ki[2], Kd[2], DIRECT);
//PID PID4(&Input4, &Output4, &Setpoint4, Kp[3], Ki[3], Kd[3], DIRECT);
//
//const int enA[4] = {2,20,0,0};
//const int enB[4] = {3,21,0,0};
//
////const int M1A[4] = {8,10,0,0};
////const int M1B[4] = {9,11,0,0};
//
//float distance[4] = {0,0,0,0};
//float prev_distance[4] = {0,0,0,0};
//float velocity[4] = {0,0,0,0};
//
//float prev_ms[4] = {0,0,0,0};
//
//volatile bool A[4] = {0,0,0,0};
//volatile bool B[4] = {0,0,0,0};
//
//float GR = 0.50; //diameter = 0.135m
//
//int COUNT[4] = {0,0,0,0};
//
//int dir[4] = {0,0,0,0};
//
//void enA1Update(){
//  A[0] = !A[0];
//  if (A[0] == 1){
//    if (A[0] == B[0]){
//      distance[0] += GR;
//    }
//    else if (A[0] != B[0]){
//      distance[0] -= GR;
//    }
//  }
//}
//
//void enB1Update(){
//  B[0] = !B[0];
//}
//
//
//void enA2Update(){
//  A[1] = !A[1];
//  if (A[1] == 1){
//    if (A[1] == B[1]){
//      distance[1] += GR;
//    }
//    else if (A[1] != B[1]){
//      distance[1] -= GR;
//    }
//  }
//}
//
//void enB2Update(){
//  B[1] = !B[1];
//}
//
//
//void enA3Update(){
//  A[2] = !A[2];
//  if (A[2] == 1){
//    if (A[2] == B[2]){
//      distance[2] += GR;
//    }
//    else if (A[2] != B[3]){
//      distance[2] -= GR;
//    }
//  }
//}
//
//void enB3Update(){
//  B[2] = !B[2];
//}
//
//void enA4Update(){
//  A[3] = !A[3];
//  if (A[3] == 1){
//    if (A[3] == B[3]){
//      distance[3] += GR;
//    }
//    else if (A[3] != B[3]){
//      distance[3] -= GR;
//    }
//  }
//}
//
//void enB4Update(){
//  B[3] = !B[3];
//}
//
//float simple_rmcs_control(double Speed_,int i)
//{
//      analogWrite(M1A[i],Speed_);//C
//      analogWrite(M1B[i],0);
//}

//void init_encoder(int i){
//  /* Setup the interrupt pin */
//  // put your setup code here, to run once:
//  pinMode(enA[i], INPUT);
//  pinMode(enB[i], INPUT);
//  digitalWrite(enA[i], HIGH);
//  digitalWrite(enB[i], HIGH);
//  
//  if (i == 0){
//    attachInterrupt(digitalPinToInterrupt(enA[i]), enA1Update, CHANGE);
//    attachInterrupt(digitalPinToInterrupt(enB[i]), enB1Update, CHANGE);
//  }
//  
//  else if (i == 1){
//    attachInterrupt(digitalPinToInterrupt(enA[i]), enA2Update, CHANGE);
//    attachInterrupt(digitalPinToInterrupt(enB[i]), enB2Update, CHANGE);
//  }
//  
//  else if (i == 2){
//    attachInterrupt(digitalPinToInterrupt(enA[i]), enA3Update, CHANGE);
//    attachInterrupt(digitalPinToInterrupt(enB[i]), enB3Update, CHANGE);
//  }
//  
//  else if (i == 3){
//    attachInterrupt(digitalPinToInterrupt(enA[i]), enA3Update, CHANGE);
//    attachInterrupt(digitalPinToInterrupt(enB[i]), enB3Update, CHANGE);
//  }
//}
//
//void disp_values(int i){
//  
//  if (millis() > prev_ms[i]+5){
//      velocity[i] = abs(distance[i] - prev_distance[i])/ (millis() - prev_ms[i]);
//      prev_distance[i] = distance[i];    
//      //Serial.print(velocity[i]*dir[i]);
//      //Serial.print(",");
//      //Serial.println(setpoint[i]);
//      prev_ms[i] = millis();
//  }
//}

//void init_PID(int i){
//    setpoint[i] = -0.3;
//    if (i == 0){
//       Setpoint1 = abs(setpoint[i]);
//       PID1.SetMode(AUTOMATIC);
//    }
//    else if (i == 1){
//       Setpoint2 = abs(setpoint[i]);
//       PID2.SetMode(AUTOMATIC);
//    }    
//    else if (i == 2){
//       Setpoint3 = abs(setpoint[i]);
//       PID3.SetMode(AUTOMATIC);
//    }    
//    else if (i == 3){
//       Setpoint4 = abs(setpoint[i]);
//       PID4.SetMode(AUTOMATIC);
//    }    
//}

void init_rmcs()
{
  
  for (int i = 0; i<2; i++){
//    init_encoder(i); 
//    init_PID(i);  
    pinMode(M1A[i], OUTPUT);
    pinMode(M1B[i], OUTPUT);
  }
  Serial.println("Initialisation complete.");
}

//float rmcs_control(double Setpoint,int i)
//{
//  double Speed_;
//  for (int i = 0; i<2; i++){
//    if (i == 0){
//      PID1.Compute();
//      Input1 = velocity[i];
//      Speed_ = Output1;
//      Setpoint1 = Setpoint;
//    }
//    else if (i == 1){
//      PID2.Compute();
//      Input2 = velocity[i];
//      Speed_ = Output2;
//      Setpoint2 = Setpoint;
//    }
//    else if (i == 2){
//      PID3.Compute();
//      Input3 = velocity[i];
//      Speed_ = Output3;
//      Setpoint3 = Setpoint;
//    }
//    else if (i == 3){
//      PID4.Compute();
//      Input4 = velocity[i];
//      Speed_ = Output4;
//      Setpoint4 = Setpoint;
//    }    
//    disp_values(i);
//  
//    dir[i] = setpoint[i]/abs(setpoint[i]);
//    
//    if (dir[i] == 1){
//      analogWrite(M1A[i],Speed_);//C
//      analogWrite(M1B[i],0);
//      //Serial.println("Clokwise");
//    }
//    else if (dir[i] == -1){
//      analogWrite(M1A[i],0);     //AC
//      analogWrite(M1B[i],Speed_);
//      //Serial.println("Counter Clokwise");
//    }
//    if (COUNT[i] > 100){
//      COUNT[i] = 0;
//      setpoint[i] += 0.1;
//    }
//    if (i == 0){
//       Setpoint1 = abs(setpoint[i]);
//    }
//    else if (i == 1){
//       Setpoint2 = abs(setpoint[i]);
//    }
//    else if (i == 2){
//       Setpoint3 = abs(setpoint[i]);
//    }
//    else if (i == 3){
//       Setpoint4 = abs(setpoint[i]);
//    }
//    COUNT[i]++;
//    delay(100);
//  }
//  Serial.println(String(velocity[0])+"  "+String(velocity[1])+"  "+String(Setpoint1)+"  "+String(Setpoint2));
//}

void init_servo(){
    pinMode(0,OUTPUT);
    pinMode(1,OUTPUT);    
    
    pinMode(10,OUTPUT);
    pinMode(11,OUTPUT);
    pinMode(12,OUTPUT);
    pinMode(13,OUTPUT);
      
    scanner.attach(40);
    scanner.write(90);
    
    slider.attach(1);
    slider.write(90);
    
    servo[0].attach(10);
    servo[1].attach(11);
    servo[2].attach(12);
    servo[3].attach(13);
    servo[0].write(90);
    servo[1].write(90);
    servo[2].write(90);
    servo[3].write(90);
}

void stop_motor(){

  for(int i = 0;i < 4;i++){
    analogWrite(M1A[i],LOW);
    analogWrite(M1B[i],LOW);
  }
}

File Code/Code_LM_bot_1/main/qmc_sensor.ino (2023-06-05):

/*
===============================================================================================================
QMC5883LCompass.h Library Azimuth Example Sketch
Learn more at [https://github.com/mprograms/QMC5883Compas]
===============================================================================================================
v0.3 - June 12, 2019
Written by MRPrograms 
Github: [https://github.com/mprograms/]

Release under the GNU General Public License v3
[https://www.gnu.org/licenses/gpl-3.0.en.html]
===============================================================================================================
*/
//-----------------------------------------------------------------------
//--------------------------Compass Test --------------------------------
//-----------------------------------------------------------------------

#include <QMC5883LCompass.h>

QMC5883LCompass compass;
float  timeout = 100*100,time_cal =  0.0, start_time = 0.0;
float  min_x = -100000, min_y = -100000, max_x = 100000, max_y = 100000, phi = 0.0;

void init_qmc() {
  //Serial.begin(9600);
  
  compass.init();
  compass.setMode(0x01, 0x0C, 0x00, 0x00);                  //Continuos, 200 Hz, 2G, 512 (MODE, ODR, RNG, OSR)
  compass.setCalibration ( -1090, 16, -1257, 0, -1, 1183);
  Serial.println("Rotate the sensor from 0 to 360");
  delay(1000);
  
  digitalWrite(IN1[0],HIGH);
  digitalWrite(IN2[0],LOW);
  digitalWrite(EN[0],100);
  
  digitalWrite(IN1[1],LOW);
  digitalWrite(IN2[1],HIGH);
  digitalWrite(EN[1],100);
  
  digitalWrite(IN1[2],HIGH);
  digitalWrite(IN2[2],LOW);
  digitalWrite(EN[2],100);
  
  digitalWrite(IN1[3],LOW);
  digitalWrite(IN2[3],HIGH);
  digitalWrite(EN[3],100);
  delay(2000);
  float startTime = millis();
  while(timeout > time_cal){
      // Read compass values
       compass.read();
    
      // Return XYZ readings
      float x = compass.getX();
      float y = compass.getY();
      if(x > min_x)
        min_x = x;
      if(x < max_x)
        max_x = x; 
      if(y > min_y)
        min_y = y;
      if(y < max_y)
        max_y = y;
        
     Serial.println(String(max_x)+String("\t")+String(max_y)+String("\t")+String(min_x)+String("\t")+String(min_y)+String("\t"));
     time_cal = millis() - start_time;       
  }
  stop_motor();
  delay(2000);
}

float getPhi() {

  // Read compass values

  compass.read();
  
  // Return XYZ readings
  float map_x = map(compass.getX(),min_x,max_x,  255,-255);
  float map_y = map(compass.getY(),min_y,max_y, -255, 255);
  float mag = sqrt(pow(map_x,2) + pow(map_y,2));
  //float theta = radians(90);
  //map_x =  map_x*(0) + map_y*(1);
  //map_y =  map_x*(-1) + map_y*(0);
  
  phi = degrees(acos(abs(map_y)/mag));
  //second quadrant
  if (map_x > 0 && map_y > 0){
     phi = 180.0 - phi;
  }
  //Third quadrant
  else if (map_x < 0 && map_y > 0){
     phi = 180.0 + phi;
  }
  //Fourth Quadrant
  else if (map_x < 0 && map_y < 0){
     phi = 360 - phi;
  }
  //Serial.print(map_x);Serial.print("\t");Serial.print(map_y);Serial.print("\t");Serial.println(phi);
  return phi ; 
}
